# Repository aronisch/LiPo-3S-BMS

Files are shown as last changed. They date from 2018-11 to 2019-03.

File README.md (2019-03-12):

# LiPo-3S-BMS
Battery Management System based on bq78350R1 and bq79620 - Designed for 3S LiPo batteries

- Originally created for the [INSA Rennes robot club](https://github.com/clubrobot)
- Schematics and PCB made with Autodesk Eagle
- FETs controlled on the low-side (communication based on ground connection not possible outside the BMS)
- Allow the atmega on the pcb to get the SoC, the voltage, current, remaining time and all the information available from the bq78350R1 (small C++ class using Arduino Wire provided)
- Version 1.1 removes the temperature sensor connector, has a smaller footprint and add a SMB connector for the EV2400 which is the development module necessary to interface the BMS with bqStudio on PC.

## TODO
- Reduce footprint even further
- Change FET control to high-side
- Look for alternatives to the atmega to get battery status (maybe remove it or put the 5V regulator after the protection)
- Use right-angle connectors instead of straight ones
- Better protect SMB port
- Use XT90 Connectors instead of Dean ?

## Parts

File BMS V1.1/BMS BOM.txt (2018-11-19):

Partlist exported from /Users/arthur/OneDrive/Documents/Projets/eagle/BMS Club Robot/BMS Schematic.sch at 28/12/2017 13:47

Qty Value               Device                                          Package              Parts                                                                  Description                                          DATASHEET                                     DIGIKEY     ELEMENT14 MANUFACTURER_PART_NUMBER MF MPN                    OC_FARNELL OC_NEWARK OTHER PROD_ID     SPICEPREFIX TP_SIGNAL_NAME URL                                                                                            VALUE           VENDOR

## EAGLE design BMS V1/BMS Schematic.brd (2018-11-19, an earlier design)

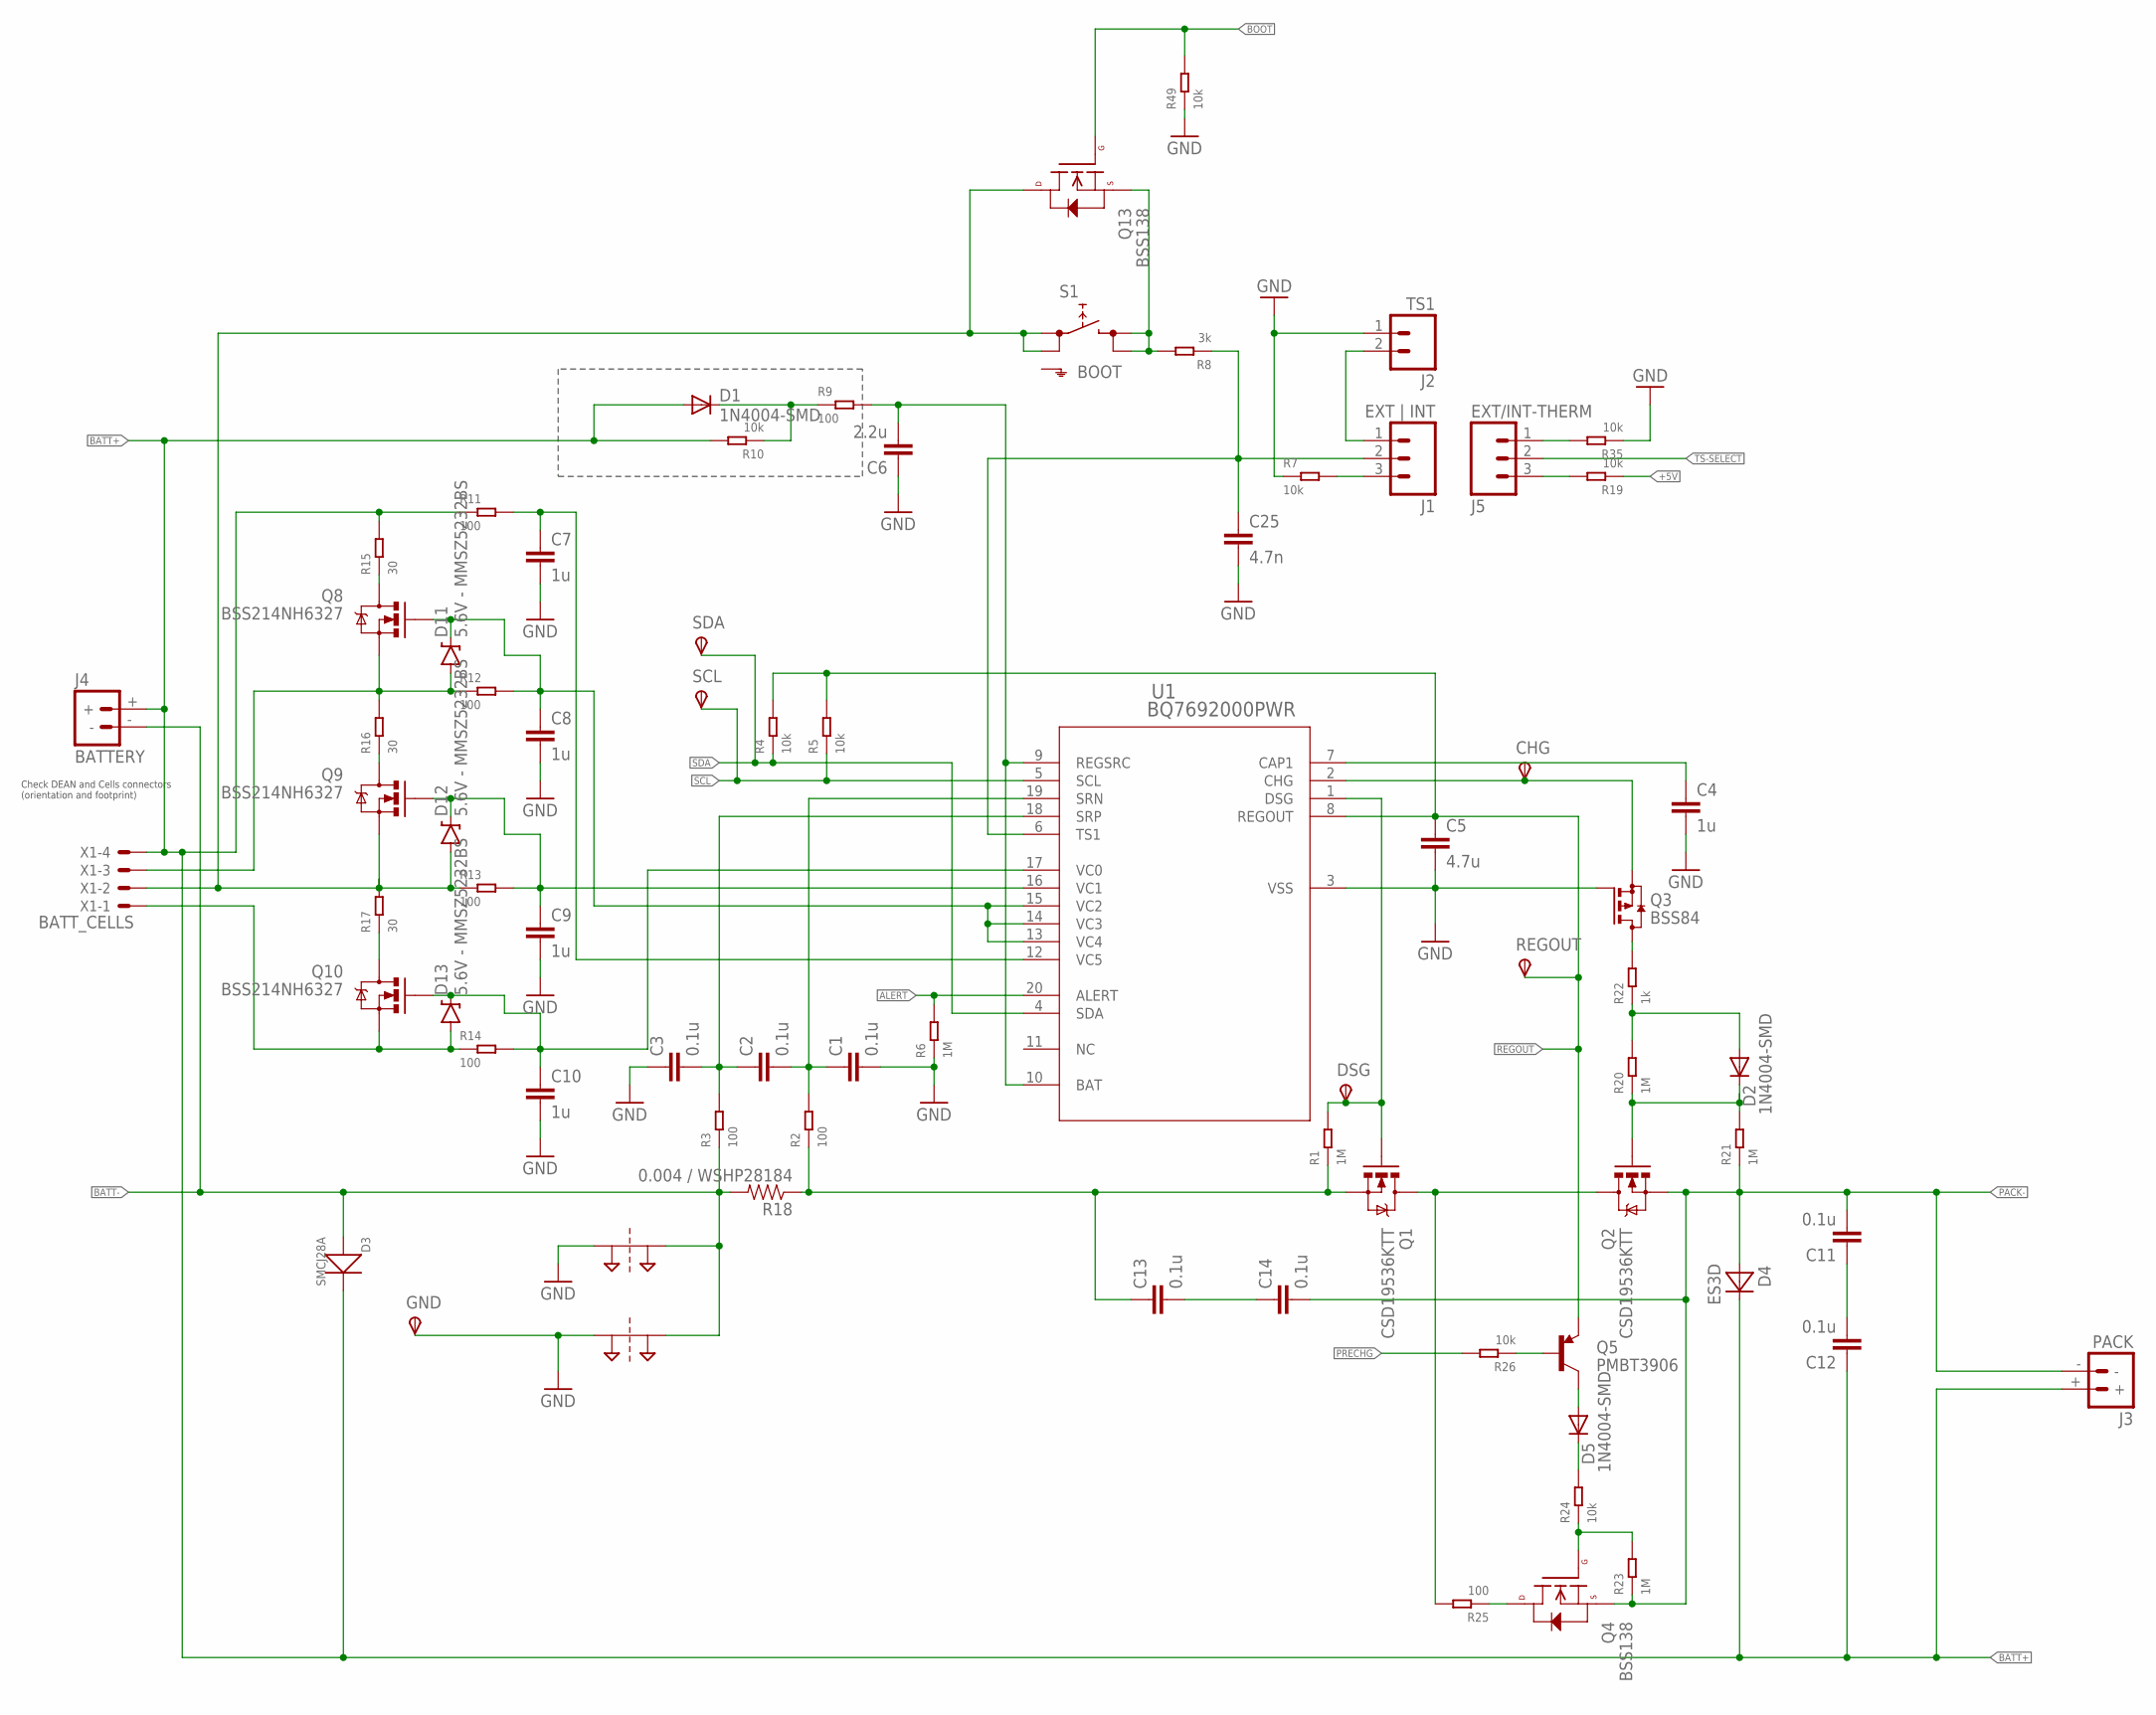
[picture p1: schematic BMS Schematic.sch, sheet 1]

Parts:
C1, C2, C3, C11, C12, C13, C14: 0.1u; 0805
C4, C7, C8, C9, C10: 1u; 0805
C5: 4.7u; 0805
C6: 2.2u; C1206
C25: 4.7n; 0805
CHG: TPSB2,54; B2,54
D1, D2, D5: 1N4004-SMD; DO-214
D3: SMCJ28A; DO-214AB
D4: ES3D; SMC
D11, D12, D13: 5.6V - MMSZ5232BS; SOD-323
DSG: TPSB2,54; B2,54
GND: GND; P1-17
J1: EXT | INT; 1X03
J2: TS1; 1X02
J3: PACK; DEANS
J4: BATTERY; DEANS
J5: EXT/INT-THERM; 1X03
PT1, PT2: 2PT_GND_TIE
Q1, Q2: CSD19536KTT; TO-263/D2PAK
Q3: BSS84; SOT23
Q4, Q13: BSS138; SOT23-3
Q5: PMBT3906; SOT23-3
Q8, Q9, Q10: BSS214NH6327; SOT23-3
R1, R6, R20, R21, R23: 1M; R0805
R2, R3, R9, R11, R12, R13, R14: 100; R0805
R4, R5, R7, R10, R19, R24, R26, R35, R49: 10k; R0805
R8: 3k; R0805
R15, R16, R17: 30; R2512
R18: 0.004 / WSHP28184; 2512
R22: 1k; R0805
R25: 100; R2512
REGOUT: TPSB2,54; B2,54
S1: BOOT; SKHMPXE010
SCL: TPSB2,54; B2,54
SDA: TPSB2,54; B2,54
U1: BQ7692000PWR; PW20
X1: BATT_CELLS; 70543-04

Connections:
+5V: R19.1; also elsewhere on the board
ALERT: R6.2, U1.20 (ALERT); also elsewhere on the board
BATT+: C12.1, D1.A, D3.2 (-), D4.C, J3.+, J4.+, R10.2, R11.1, R15.2, X1.4; also elsewhere on the board
BATT-: D3.1 (+), J4.-, PT1.P$2, PT2.P$2, R3.1, R18.2
BOOT: Q13.1 (G), R49.2; also elsewhere on the board
CHG: CHG.TP, Q3.2 (S), U1.2 (CHG)
DSG: DSG.TP, Q1.1 (G), R1.2, U1.1 (DSG)
DSG-CHG: Q1.2 (D), Q2.2 (D), R25.2
GND: C1.2, C3.1, C4.2, C5.2, C6.1, C7.2, C8.2, C9.2, C10.2, C25.2, GND.TP, J2.1, PT1.P$1, PT2.P$1, Q3.1 (G), R6.1, R7.1, R35.1, R49.1, U1.3 (VSS); also elsewhere on the board
unnamed: C2.1, C3.2, R3.2, U1.18 (SRP)
unnamed: C1.1, C2.2, R2.2, U1.19 (SRN)
unnamed: C25.1, J1.2, R8.1, U1.6 (TS1)
unnamed: C6.2, R9.2, U1.9 (REGSRC), U1.10 (BAT)
unnamed: C4.1, U1.7 (CAP1)
unnamed: J1.1, J2.2
unnamed: J1.3, R7.2
unnamed: D1.C, R9.1, R10.1
unnamed: Q13.2 (S), R8.2, S1.3 (2.1), S1.4 (2.2)
unnamed: D13.A, Q10.2 (S), R14.1, X1.1
unnamed: C7.1, R11.2, U1.12 (VC5)
unnamed: Q8.3 (D), R15.1
unnamed: C10.1, D13.C, Q10.1 (G), R14.2, U1.17 (VC0)
unnamed: J5.3, R19.2
unnamed: D11.A, Q8.2 (S), R12.1, R16.2, X1.3
unnamed: Q9.3 (D), R16.1
unnamed: D2.C, Q2.1 (G), R20.1, R21.2
unnamed: C8.1, D11.C, Q8.1 (G), R12.2, U1.13 (VC4), U1.14 (VC3), U1.15 (VC2)
unnamed: Q10.3 (D), R17.1
unnamed: C11.1, C12.2
unnamed: D2.A, R20.2, R22.1
unnamed: D12.A, Q9.2 (S), Q13.3 (D), R13.1, R17.2, S1.1 (1.1), S1.2 (1.2), X1.2
unnamed: Q3.3 (D), R22.2
unnamed: C13.2, C14.1
unnamed: Q4.1 (G), R23.2, R24.1
unnamed: D5.C, R24.2
unnamed: D5.A, Q5.3 (C)
unnamed: Q5.1 (B), R26.1
unnamed: Q4.3 (D), R25.1
unnamed: J5.1, R35.2
unnamed: C9.1, D12.C, Q9.1 (G), R13.2, U1.16 (VC1)
PACK-: C11.2, C14.2, D4.A, J3.-, Q2.3 (S), Q4.2 (S), R21.1, R23.1
PRECHG: R26.2; also elsewhere on the board
REGOUT: C5.1, Q5.2 (E), R4.2, R5.2, REGOUT.TP, U1.8 (REGOUT); also elsewhere on the board
RSNS-DSG: C13.1, Q1.3 (S), R1.1, R2.1, R18.1
SCL: R5.1, SCL.TP, U1.5 (SCL); also elsewhere on the board
SDA: R4.1, SDA.TP, U1.4 (SDA); also elsewhere on the board
TS-SELECT: J5.2; also elsewhere on the board

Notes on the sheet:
Check DEAN and Cells connectors (orientation and footprint)

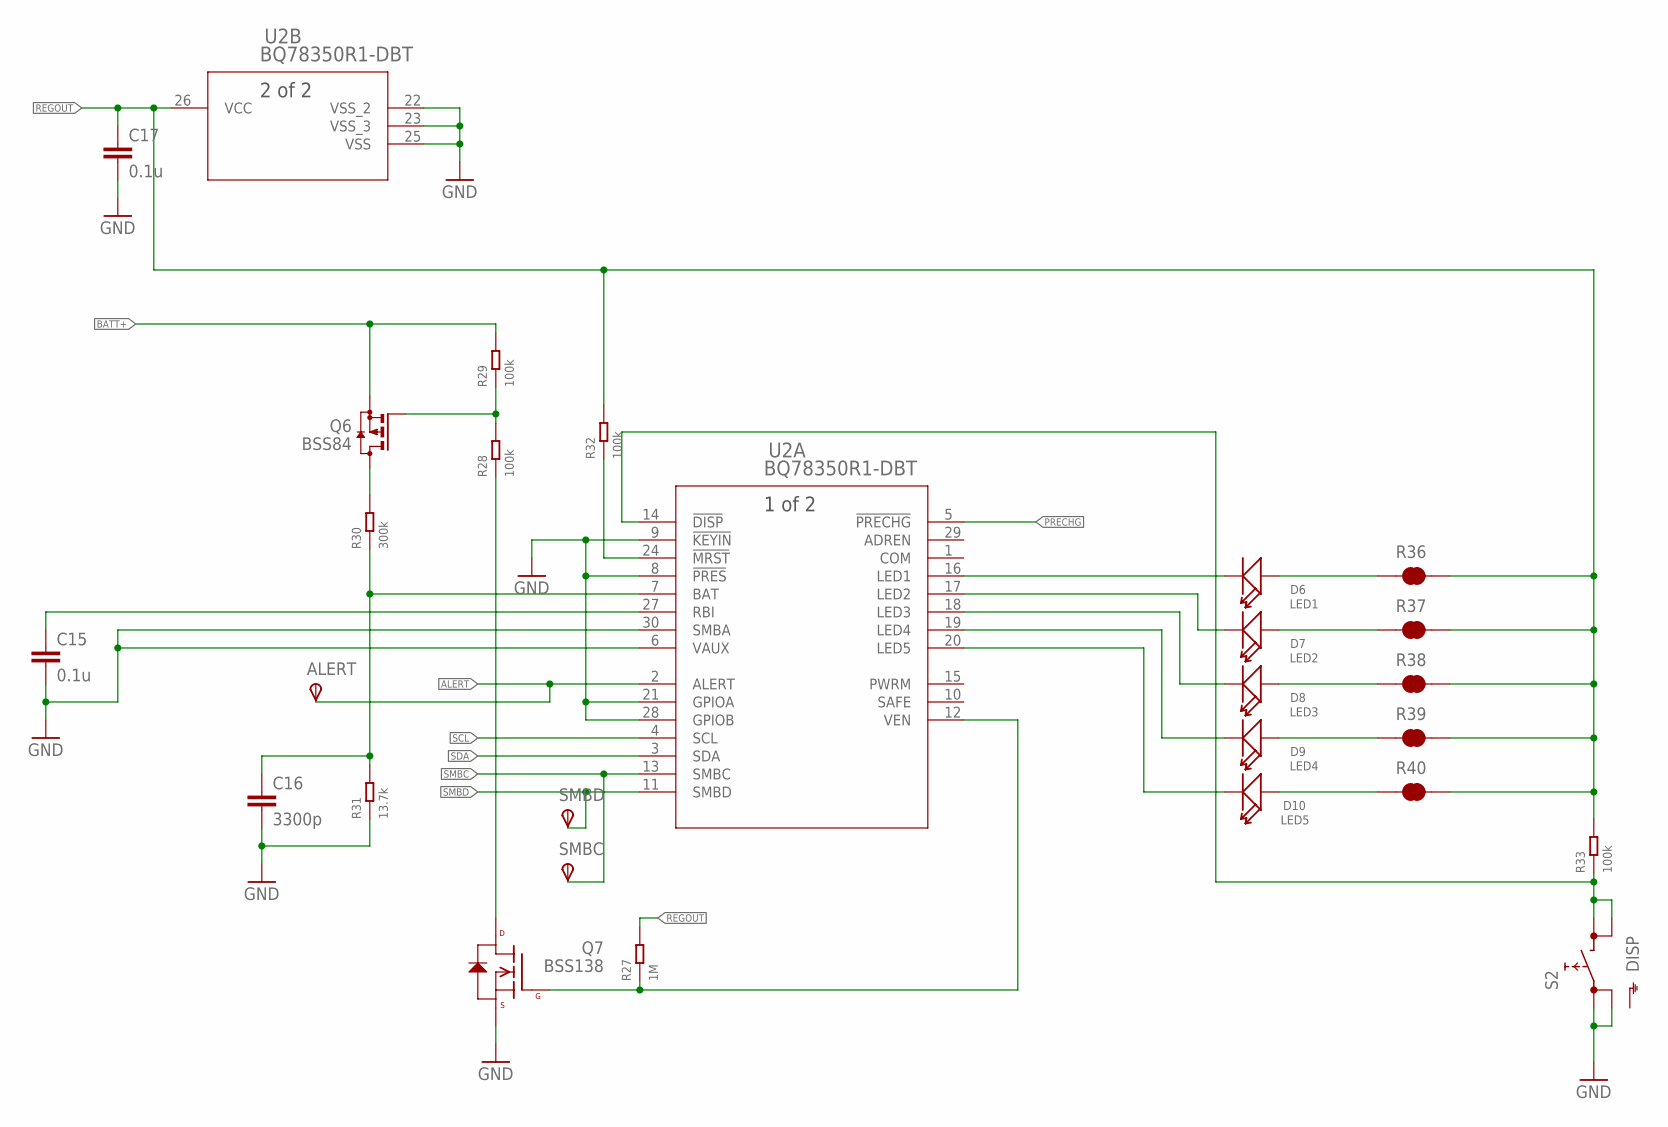
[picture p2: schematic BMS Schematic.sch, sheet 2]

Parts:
ALERT: TPSB2,54; B2,54
C15, C17: 0.1u; 0805
C16: 3300p; 0805
D6: LED1; LED-0805
D7: LED2; LED-0805
D8: LED3; LED-0805
D9: LED4; LED-0805
D10: LED5; LED-0805
Q6: BSS84; SOT23
Q7: BSS138; SOT23-3
R27: 1M; R0805
R28, R29, R32, R33: 100k; R0805
R30: 300k; R0805
R31: 13.7k; R0805
R36, R37, R38, R39, R40: JUMPER-NC-0805; R0805
S2: DISP; SKHMPXE010
SMBC: TPSB2,54; B2,54
SMBD: TPSB2,54; B2,54
U2: BQ78350R1-DBT; DBT30

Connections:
ALERT: ALERT.TP, U2.2 (ALERT); also elsewhere on the board
BATT+: Q6.2 (S), R29.2; also elsewhere on the board
GND: C15.2, C16.2, C17.2, Q7.2 (S), R31.1, S2.1 (1.1), S2.2 (1.2), U2.6 (VAUX), U2.8 (!PRES), U2.9 (!KEYIN), U2.21 (GPIOA), U2.22 (VSS_2), U2.23 (VSS_3), U2.25 (VSS), U2.28 (GPIOB), U2.30 (SMBA); also elsewhere on the board
unnamed: C15.1, U2.27 (RBI)
unnamed: Q7.1 (G), R27.1, U2.12 (VEN)
unnamed: Q7.3 (D), R28.1
unnamed: Q6.1 (G), R28.2, R29.1
unnamed: Q6.3 (D), R30.2
unnamed: C16.1, R30.1, R31.2, U2.7 (BAT)
unnamed: R32.1, U2.24 (!MRST)
unnamed: D6.-, U2.16 (LED1)
unnamed: D7.-, U2.17 (LED2)
unnamed: D8.-, U2.18 (LED3)
unnamed: D9.-, U2.19 (LED4)
unnamed: D10.-, U2.20 (LED5)
unnamed: D6.+, R36.1
unnamed: D7.+, R37.1
unnamed: R33.1, S2.3 (2.1), S2.4 (2.2), U2.14 (!DISP)
unnamed: D8.+, R38.1
unnamed: D9.+, R39.1
unnamed: D10.+, R40.1
PRECHG: U2.5 (!PRECHG); also elsewhere on the board
REGOUT: C17.1, R27.2, R32.2, R33.2, R36.2, R37.2, R38.2, R39.2, R40.2, U2.26 (VCC); also elsewhere on the board
SCL: U2.4 (SCL); also elsewhere on the board
SDA: U2.3 (SDA); also elsewhere on the board
SMBC: SMBC.TP, U2.13 (SMBC); also elsewhere on the board
SMBD: SMBD.TP, U2.11 (SMBD); also elsewhere on the board

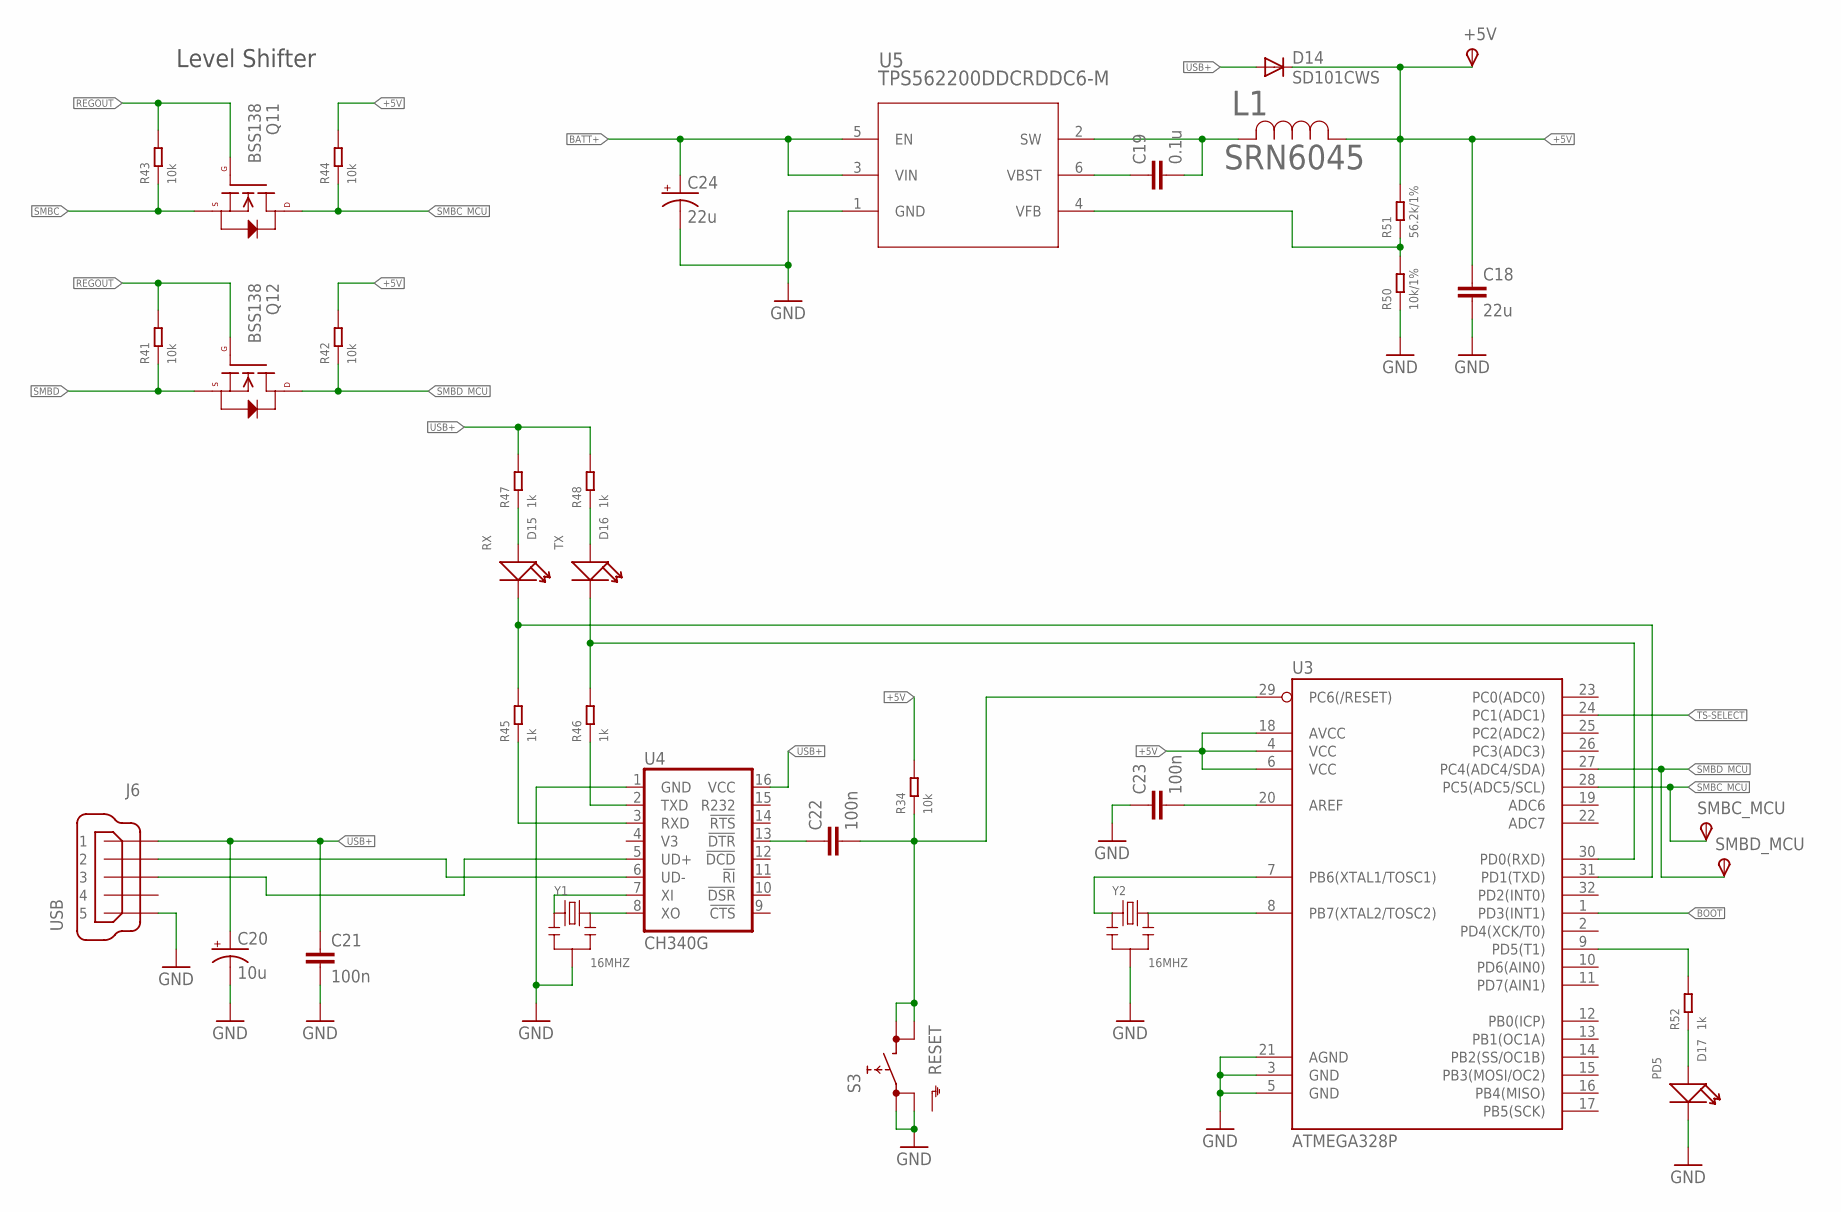
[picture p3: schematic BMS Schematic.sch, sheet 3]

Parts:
+5V: TPSB2,54; B2,54
C18: 22u; 0805
C19: 0.1u; 0805
C20: 10u; EIA3216-KIT
C21, C22, C23: 100n; 0603-CAP
C24: 22u; PANASONIC_C
D14: SD101CWS; SOD323-W
D15: RX; LED-0805
D16: TX; LED-0805
D17: PD5; LED-0805
J6: USB; USB-MINI-B_2
L1: SRN6045; IND_BOURNS_SRN6045
Q11, Q12: BSS138; SOT23-3
R34, R41, R42, R43, R44: 10k; R0805
R45, R46, R47, R48, R52: 1k; R0805
R50: 10k/1%; R0805
R51: 56.2k/1%; R0805
S3: RESET; SKHMPXE010
SMBC_MCU: TPSB2,54; B2,54
SMBD_MCU: TPSB2,54; B2,54
U3: ATMEGA328P; TQFP32-08
U4: CH340G; SO016
U5: TPS562200DDCRDDC6-M; DDC6-M
Y1, Y2: 16MHZ; X3-SMD-3.6X1.3X0.8MM

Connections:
+5V: +5V.TP, C18.1, D14.C, L1.1, R34.2, R42.2, R44.2, R51.2, U3.4 (VCC), U3.6 (VCC), U3.18 (AVCC); also elsewhere on the board
BATT+: C24.+, U5.3 (VIN), U5.5 (EN); also elsewhere on the board
BOOT: U3.1 (PD3(INT1)); also elsewhere on the board
GND: C18.2, C20.C (-), C21.2, C23.1, C24.-, D17.-, J6.1 (5), R50.1, S3.1 (1.1), S3.2 (1.2), U3.3 (GND), U3.5 (GND), U3.21 (AGND), U4.1 (GND), U5.1 (GND), Y1.2, Y2.2; also elsewhere on the board
unnamed: J6.4 (2), U4.6 (UD-)
unnamed: J6.3, U4.5 (UD+)
unnamed: D15.+, R47.1
unnamed: D16.+, R48.1
unnamed: C22.1, U4.13 (!DTR)
unnamed: C22.2, R34.1, S3.3 (2.1), S3.4 (2.2), U3.29 (PC6(/RESET))
unnamed: U4.7 (XI), Y1.1
unnamed: U4.8 (XO), Y1.3
unnamed: R45.1, U4.3 (RXD)
unnamed: U3.8 (PB7(XTAL2/TOSC2)), Y2.3
unnamed: U3.7 (PB6(XTAL1/TOSC1)), Y2.1
unnamed: R46.1, U4.2 (TXD)
unnamed: D15.-, R45.2, U3.31 (PD1(TXD))
unnamed: D16.-, R46.2, U3.30 (PD0(RXD))
unnamed: C23.2, U3.20 (AREF)
unnamed: R50.2, R51.1, U5.4 (VFB)
unnamed: C19.1, U5.6 (VBST)
unnamed: R52.2, U3.9 (PD5(T1))
unnamed: D17.+, R52.1
REGOUT: Q11.1 (G), Q12.1 (G), R41.2, R43.2; also elsewhere on the board
SMBC: Q11.2 (S), R43.1; also elsewhere on the board
SMBC_MCU: Q11.3 (D), R44.1, SMBC_MCU.TP, U3.28 (PC5(ADC5/SCL))
SMBD: Q12.2 (S), R41.1; also elsewhere on the board
SMBD_MCU: Q12.3 (D), R42.1, SMBD_MCU.TP, U3.27 (PC4(ADC4/SDA))
SW: C19.2, L1.2, U5.2 (SW)
TS-SELECT: U3.24 (PC1(ADC1)); also elsewhere on the board
USB+: C20.A (+), C21.1, D14.A, J6.5 (1), R47.2, R48.2, U4.16 (VCC)

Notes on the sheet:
Level Shifter

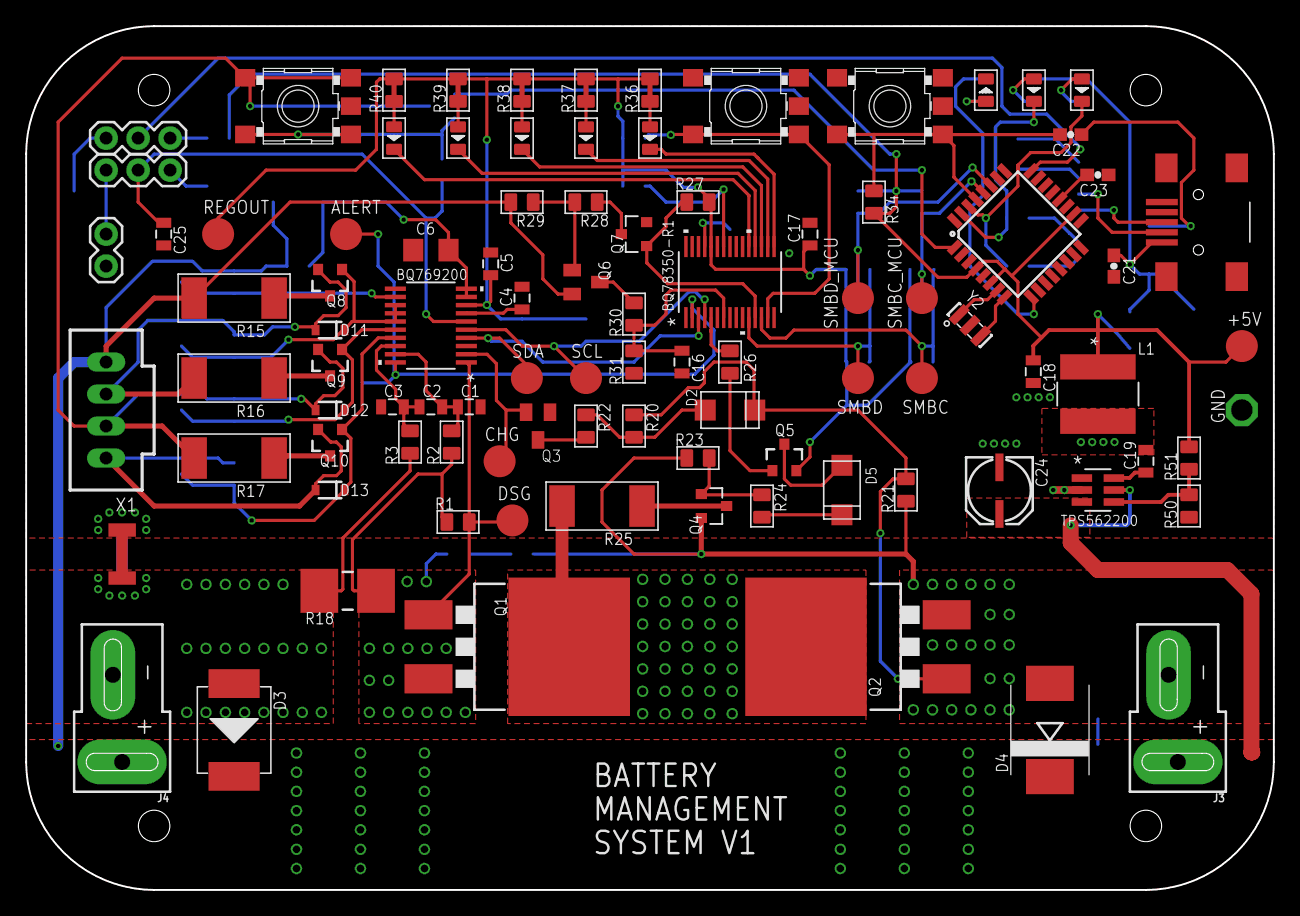
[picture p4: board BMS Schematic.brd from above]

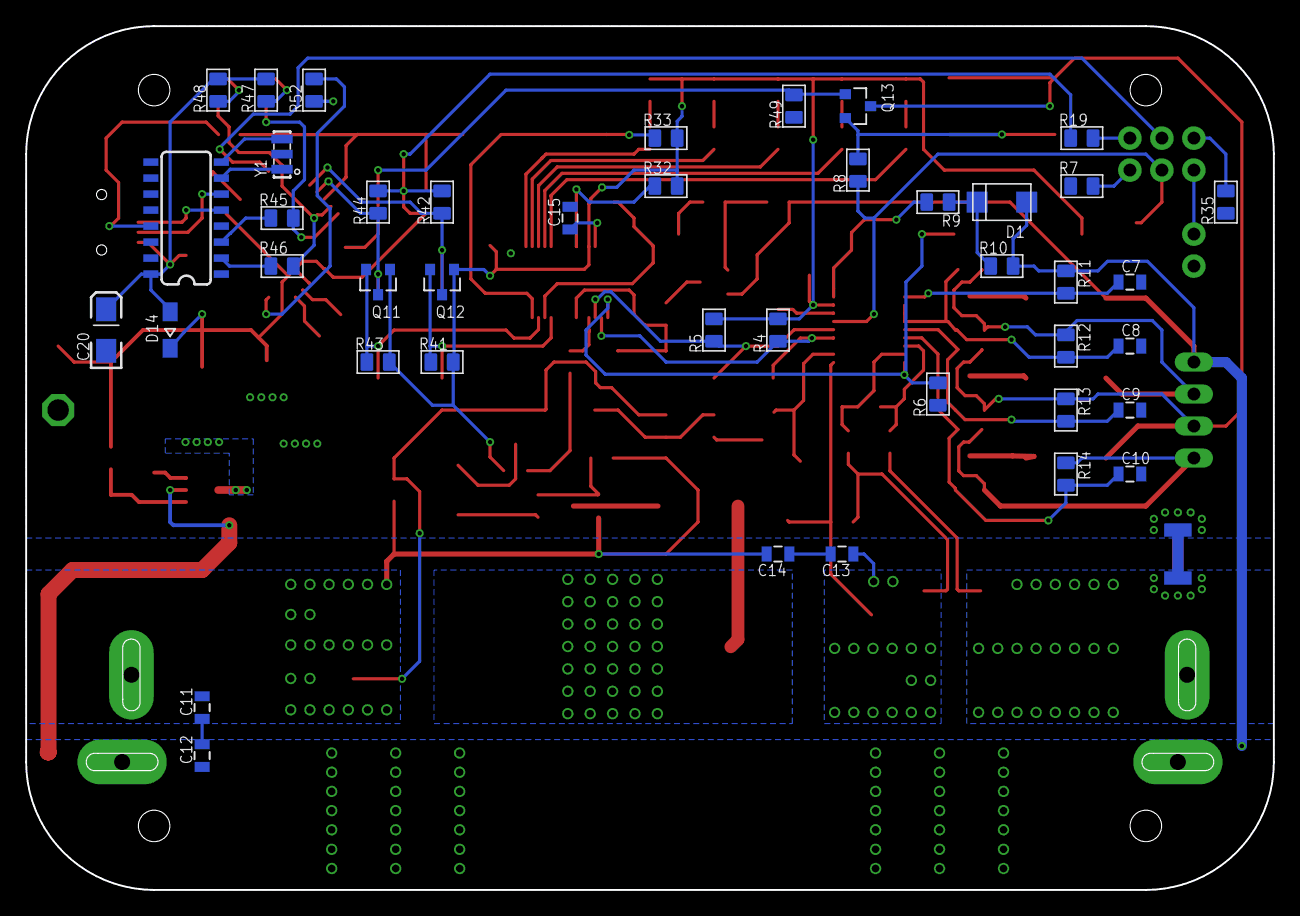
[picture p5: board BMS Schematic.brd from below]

Board: 2 copper layers, 99.1 x 68.6 mm, 139 parts (43 on the bottom side), 90 nets.

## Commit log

2018-11-19 Add V1 and V1.1 eagle files with first bms lib
    [BMS Schematic.brd, BMS Schematic.sch]
2018-11-19 Rename BMS Schematic.html to BMS BOM.html

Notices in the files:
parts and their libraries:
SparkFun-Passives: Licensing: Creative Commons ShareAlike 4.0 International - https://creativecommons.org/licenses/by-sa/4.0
